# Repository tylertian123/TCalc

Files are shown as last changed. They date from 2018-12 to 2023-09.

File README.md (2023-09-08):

# TCalc
Source code for an STM32 calculator. This repository contains the firmware source code for both the main and keyboard processors as well as the custom schematics.

Some notable features:
* Full math expression display engine
* Multi-function graphing
* Support for custom variable and function definitions
* Basic linear algebra capabilities
* Useful built-in functions such as linear system solver, polynomial regression, etc
* Built-in periodic table with extensive information for every element
* Snake and Tetris mini-games
* [Here's it playing Bad Apple because why not.](https://youtu.be/kNUgEzcHYEs) [[Separate repo here]](https://github.com/tylertian123/tcalc-badapple)

## Gallery

     


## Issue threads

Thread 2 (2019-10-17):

Status light flashes continuously

mincrmatt12, 2019-10-17:
I believe I have assembled it correctly, but the status light continuously flashes and key presses don't work.

tylertian123, 2019-10-18:
Oh that's just the "random light show" feature. Totally not a bug at all. As for why the key presses don't work - during the "random light show" the keyboard is automatically disabled so that you can focus on the beauty of the lights instead of pressing buttons.

mincrmatt12, 2019-10-18:
Is there an option to disable this "feature"? It is getting in the way due to the RNG being rather terrible at being random -- the light show often appears in long bursts.

tylertian123, 2019-10-18:
Yes, you can disable Random Light Show by disconnecting the keyboard.

mincrmatt12, 2019-10-18:
Sounds like a plan; resolving issue internally as "refused to fix"

Closed 2019-10-18.

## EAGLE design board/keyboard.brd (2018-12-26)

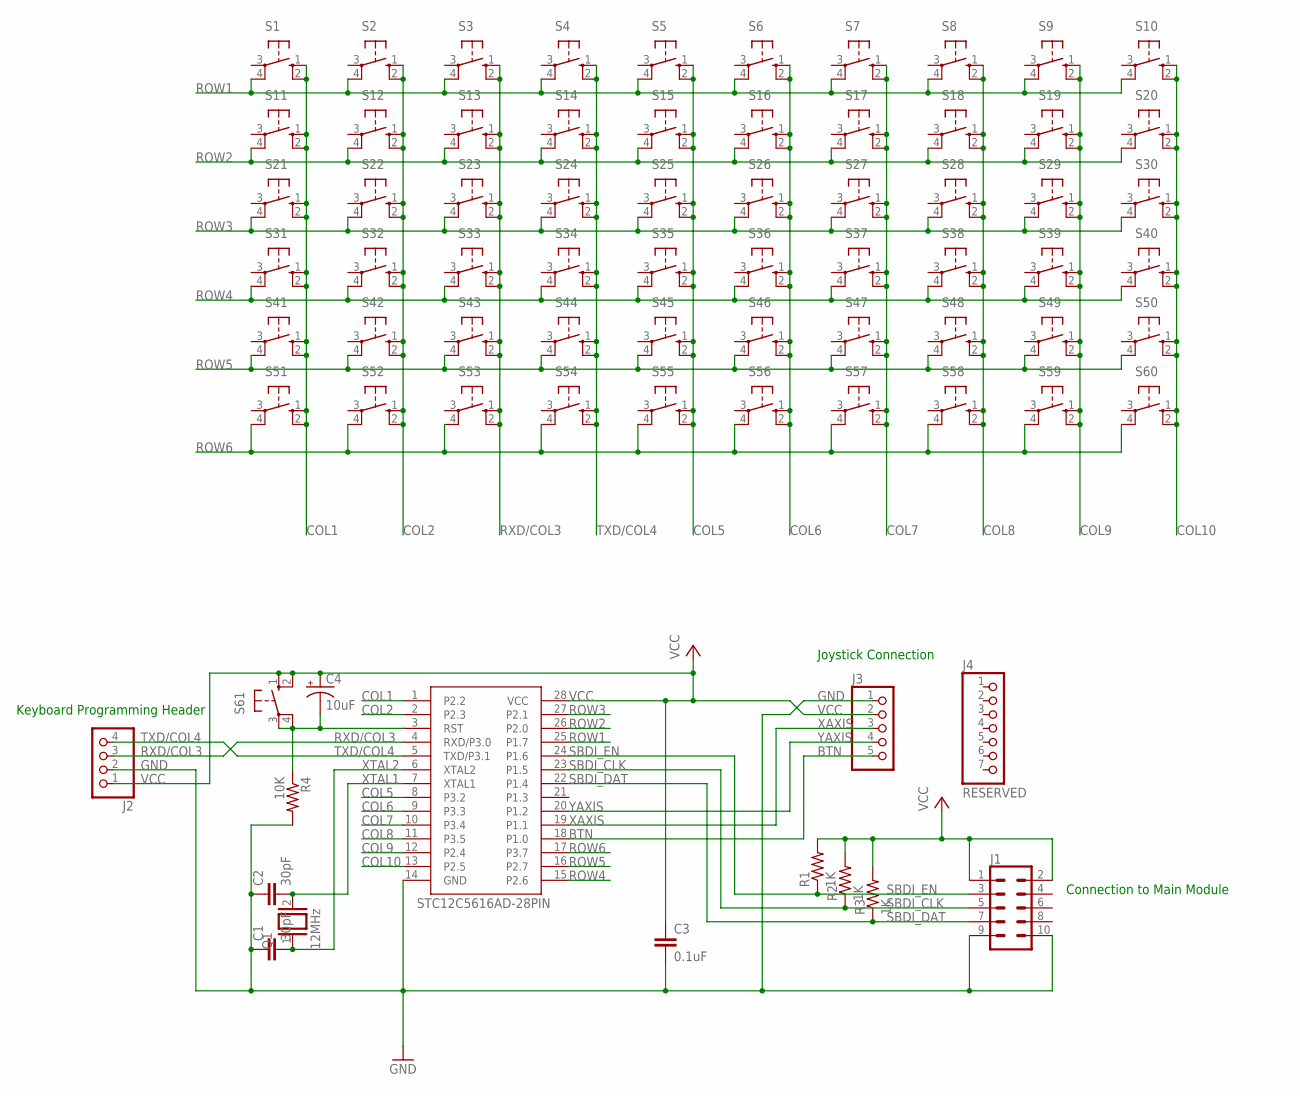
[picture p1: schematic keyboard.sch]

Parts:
C1, C2: 30pF; C025-025X050
C3: 0.1uF; C025-030X050
C4: 10uF; E1,8-4
IC1: STC12C5616AD; DIP787W45P254L3505H508Q28B
J1: CONN_05X2SHD_LOCK; 2X5-SHROUDED_LOCK
J2: PINHD-1X4; 1X04
J3: PINHD-1X5; 1X05
J4: RESERVED; 1X07
Q1: 12MHz; QS
R1, R2, R3: 1K; 0204/7
R4: 10K; 0204/7
S1, S2, S3, S4, S5, S6, S7, S8, S9, S10, S11, S12, S13, S14, S15, S16, S17, S18, S19, S20, S21, S22, S23, S24, S25, S26, S27, S28, S29, S30, S31, S32, S33, S34, S35, S36, S37, S38, S39, S40, S41, S42, S43, S44, S45, S46, S47, S48, S49, S50, S51, S52, S53, S54, S55, S56, S57, S58, S59, S60, S61: 10-XX; B3F-10XX

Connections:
BTN: IC1.18 (P1.0), J3.5
COL1: IC1.1 (P2.2), S1.1 (S), S1.2 (S1), S11.1 (S), S11.2 (S1), S21.1 (S), S21.2 (S1), S31.1 (S), S31.2 (S1), S41.1 (S), S41.2 (S1), S51.1 (S), S51.2 (S1)
COL2: IC1.2 (P2.3), S2.1 (S), S2.2 (S1), S12.1 (S), S12.2 (S1), S22.1 (S), S22.2 (S1), S32.1 (S), S32.2 (S1), S42.1 (S), S42.2 (S1), S52.1 (S), S52.2 (S1)
COL5: IC1.8 (P3.2), S5.1 (S), S5.2 (S1), S15.1 (S), S15.2 (S1), S25.1 (S), S25.2 (S1), S35.1 (S), S35.2 (S1), S45.1 (S), S45.2 (S1), S55.1 (S), S55.2 (S1)
COL6: IC1.9 (P3.3), S6.1 (S), S6.2 (S1), S16.1 (S), S16.2 (S1), S26.1 (S), S26.2 (S1), S36.1 (S), S36.2 (S1), S46.1 (S), S46.2 (S1), S56.1 (S), S56.2 (S1)
COL7: IC1.10 (P3.4), S7.1 (S), S7.2 (S1), S17.1 (S), S17.2 (S1), S27.1 (S), S27.2 (S1), S37.1 (S), S37.2 (S1), S47.1 (S), S47.2 (S1), S57.1 (S), S57.2 (S1)
COL8: IC1.11 (P3.5), S8.1 (S), S8.2 (S1), S18.1 (S), S18.2 (S1), S28.1 (S), S28.2 (S1), S38.1 (S), S38.2 (S1), S48.1 (S), S48.2 (S1), S58.1 (S), S58.2 (S1)
COL9: IC1.12 (P2.4), S9.1 (S), S9.2 (S1), S19.1 (S), S19.2 (S1), S29.1 (S), S29.2 (S1), S39.1 (S), S39.2 (S1), S49.1 (S), S49.2 (S1), S59.1 (S), S59.2 (S1)
COL10: IC1.13 (P2.5), S10.1 (S), S10.2 (S1), S20.1 (S), S20.2 (S1), S30.1 (S), S30.2 (S1), S40.1 (S), S40.2 (S1), S50.1 (S), S50.2 (S1), S60.1 (S), S60.2 (S1)
GND: C1.1, C2.1, C3.2, IC1.14 (GND), J1.9, J1.10, J2.2, J3.1, R4.2
unnamed: C4.-, IC1.3 (RST), R4.1, S61.3, S61.4 (P1)
ROW1: IC1.25 (P1.7), S1.4 (P1), S2.4 (P1), S3.4 (P1), S4.4 (P1), S5.4 (P1), S6.4 (P1), S7.4 (P1), S8.4 (P1), S9.4 (P1), S10.4 (P1)
ROW2: IC1.26 (P2.0), S11.4 (P1), S12.4 (P1), S13.4 (P1), S14.4 (P1), S15.4 (P1), S16.4 (P1), S17.4 (P1), S18.4 (P1), S19.4 (P1), S20.4 (P1)
ROW3: IC1.27 (P2.1), S21.4 (P1), S22.4 (P1), S23.4 (P1), S24.4 (P1), S25.4 (P1), S26.4 (P1), S27.4 (P1), S28.4 (P1), S29.4 (P1), S30.4 (P1)
ROW4: IC1.15 (P2.6), S31.4 (P1), S32.4 (P1), S33.4 (P1), S34.4 (P1), S35.4 (P1), S36.4 (P1), S37.4 (P1), S38.4 (P1), S39.4 (P1), S40.4 (P1)
ROW5: IC1.16 (P2.7), S41.4 (P1), S42.4 (P1), S43.4 (P1), S44.4 (P1), S45.4 (P1), S46.4 (P1), S47.4 (P1), S48.4 (P1), S49.4 (P1), S50.4 (P1)
ROW6: IC1.17 (P3.7), S51.4 (P1), S52.4 (P1), S53.4 (P1), S54.4 (P1), S55.4 (P1), S56.4 (P1), S57.4 (P1), S58.4 (P1), S59.4 (P1), S60.4 (P1)
RXD/COL3: IC1.4 (RXD/P3.0), J2.3, S3.1 (S), S3.2 (S1), S13.1 (S), S13.2 (S1), S23.1 (S), S23.2 (S1), S33.1 (S), S33.2 (S1), S43.1 (S), S43.2 (S1), S53.1 (S), S53.2 (S1)
SBDI_CLK: IC1.23 (P1.5), J1.5, R2.1
SBDI_DAT: IC1.22 (P1.4), J1.7, R3.1
SBDI_EN: IC1.24 (P1.6), J1.3, R1.1
TXD/COL4: IC1.5 (TXD/P3.1), J2.4, S4.1 (S), S4.2 (S1), S14.1 (S), S14.2 (S1), S24.1 (S), S24.2 (S1), S34.1 (S), S34.2 (S1), S44.1 (S), S44.2 (S1), S54.1 (S), S54.2 (S1)
VCC: C3.1, C4.+, IC1.28 (VCC), J1.1, J1.2, J2.1, J3.2, R1.2, R2.2, R3.2, S61.1 (S), S61.2 (S1)
XAXIS: IC1.19 (P1.1), J3.3
XTAL1: C2.2, IC1.7 (XTAL1), Q1.2
XTAL2: C1.2, IC1.6 (XTAL2), Q1.1
YAXIS: IC1.20 (P1.2), J3.4

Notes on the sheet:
Keyboard Programming Header
Joystick Connection
Connection to Main Module

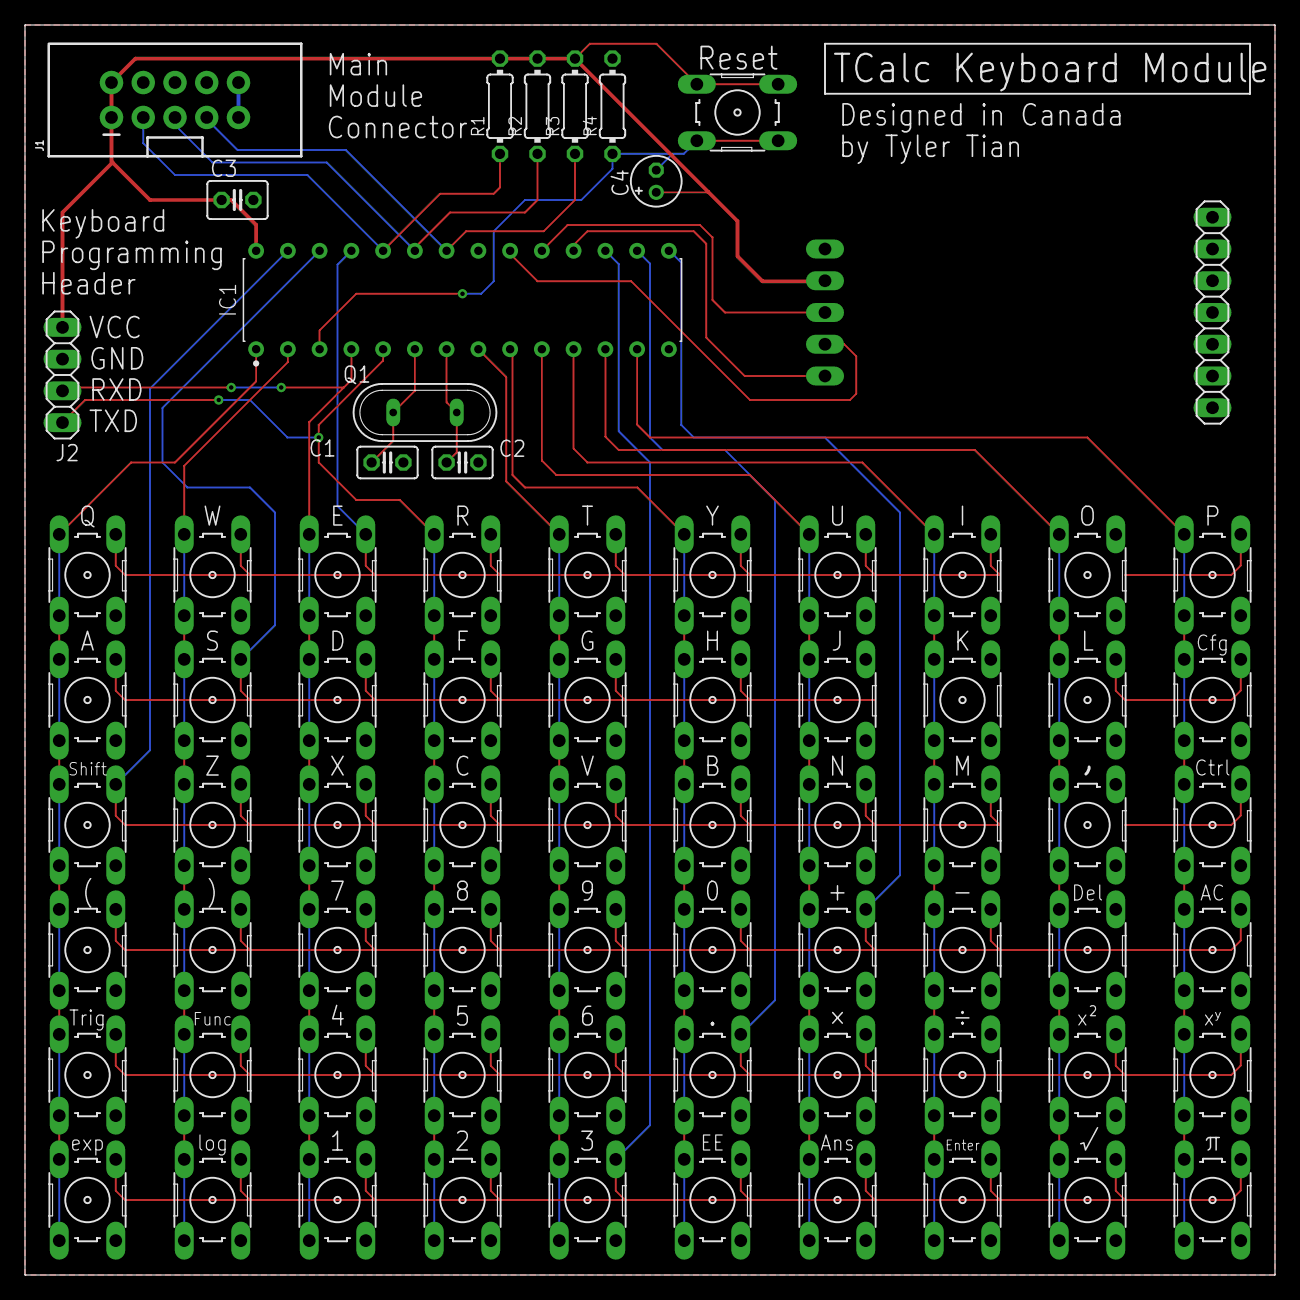
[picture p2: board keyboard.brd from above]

Board: 2 copper layers, 100.0 x 100.0 mm, 75 parts (1 on the bottom side), 27 nets.

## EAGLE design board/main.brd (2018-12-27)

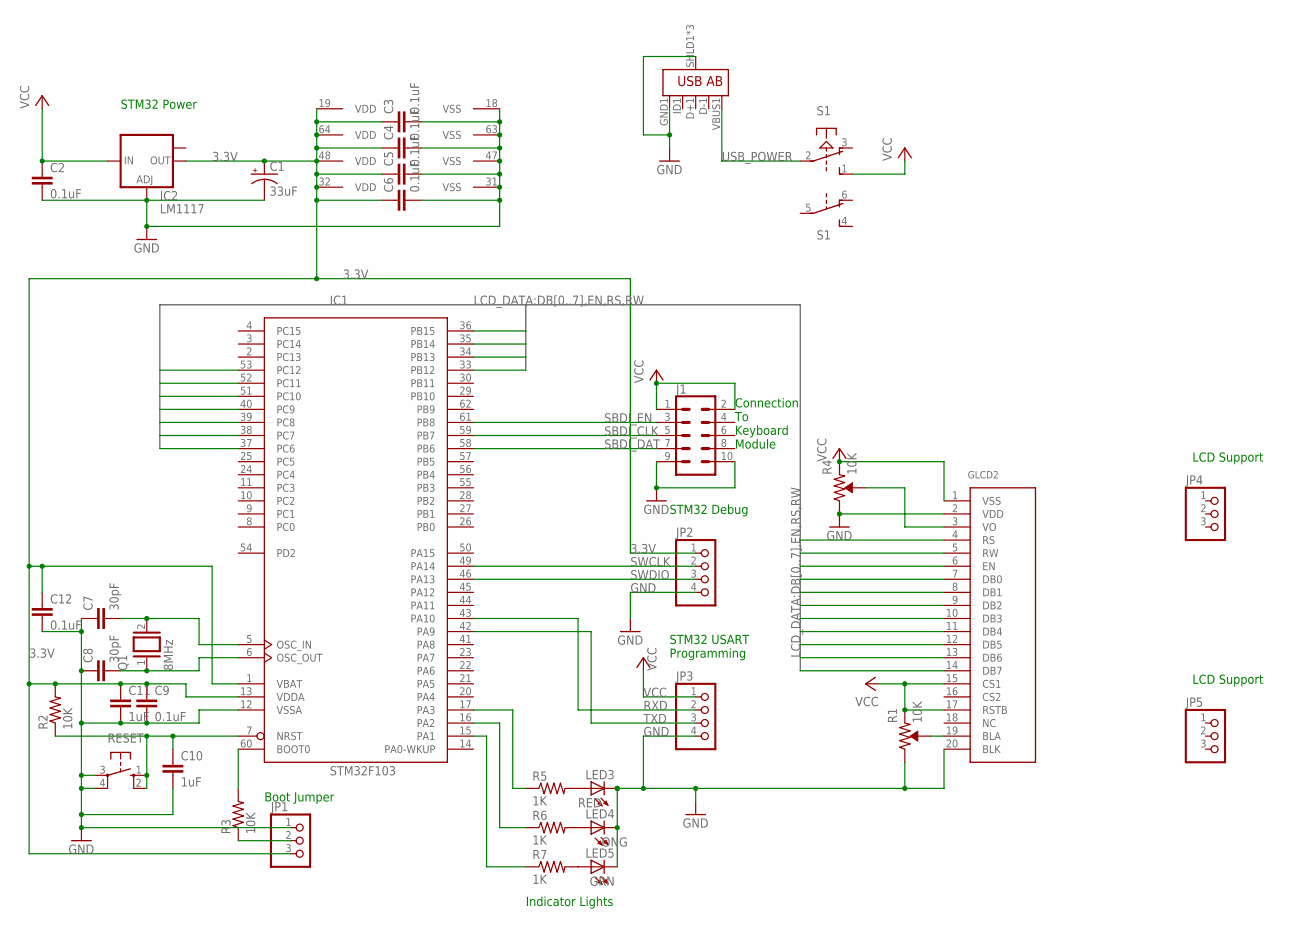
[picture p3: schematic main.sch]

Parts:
C1: 33uF; E2-5
C2, C3, C4, C5, C6, C9, C12: 0.1uF; C025-025X050
C7, C8: 30pF; C025-025X050
C10, C11: 1uF; C025-025X050
GLCD2: LCD128X64; GLCD_TRULY_128X64_20_PINES
IC1: STM32F103; LQFP64
IC2: LM1117; SOT223
J1: CONN_05X2SHD_LOCK; 2X5-SHROUDED_LOCK
JP1, JP4, JP5: PINHD-1X3; 1X03
JP2, JP3: PINHD-1X4; 1X04
LED3: RED; LED5MM
LED4: ONG; LED5MM
LED5: GRN; LED5MM
Q1: 8MHz; QS
R1, R4: 10K; TRIMPOT-PTH-3386U
R2, R3: 10K; 0204/7
R5, R6, R7: 1K; 0204/7
RESET: 10-XX; B3F-10XX
S1: PVA2R
U1: USB_AB_SMT; USB-AB-MICRO-SMD

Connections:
3.3V: C1.+, C3.1, C4.1, C5.1, C6.1, C9.1, C11.1, C12.1, IC1.1 (VBAT), IC1.13 (VDDA), IC1.19 (VDD), IC1.32 (VDD), IC1.48 (VDD), IC1.64 (VDD), IC2.2 (OUT), JP1.3, JP2.1, R2.2
DB0: GLCD2.7 (DB0), IC1.33 (PB12)
DB1: GLCD2.8 (DB1), IC1.34 (PB13)
DB2: GLCD2.9 (DB2), IC1.35 (PB14)
DB3: GLCD2.10 (DB3), IC1.36 (PB15)
DB4: GLCD2.11 (DB4), IC1.37 (PC6)
DB5: GLCD2.12 (DB5), IC1.38 (PC7)
DB6: GLCD2.13 (DB6), IC1.39 (PC8)
DB7: GLCD2.14 (DB7), IC1.40 (PC9)
EN: GLCD2.6 (EN), IC1.53 (PC12)
GND: C1.-, C2.2, C3.2, C4.2, C5.2, C6.2, C7.1, C8.1, C9.2, C10.2, C11.2, C12.2, GLCD2.2 (VDD), GLCD2.20 (BLK), IC1.12 (VSSA), IC1.18 (VSS), IC1.31 (VSS), IC1.47 (VSS), IC1.63 (VSS), IC2.1 (ADJ), J1.9, J1.10, JP1.1, JP2.4, JP3.4, LED3.K (C), LED4.K (C), LED5.K (C), R1.1, R4.1, RESET.3, RESET.4 (P1), U1.GND1 (GND), U1.SHLD1 (SHIELD), U1.SHLD2 (SHIELD), U1.SHLD3 (SHIELD)
unnamed: GLCD2.19 (BLA), R1.2
unnamed: GLCD2.3 (VO), R4.2
unnamed: LED3.A, R5.2
unnamed: LED4.A, R6.2
unnamed: C7.2, IC1.5 (OSC_IN), Q1.2
unnamed: C10.1, IC1.7 (NRST), R2.1, RESET.1 (S), RESET.2 (S1)
unnamed: C8.2, IC1.6 (OSC_OUT), Q1.1
unnamed: IC1.15 (PA1), R7.1
unnamed: IC1.60 (BOOT0), R3.2
unnamed: JP1.2, R3.1
unnamed: IC1.16 (PA2), R6.1
unnamed: IC1.17 (PA3), R5.1
unnamed: LED5.A, R7.2
RS: GLCD2.4 (RS), IC1.51 (PC10)
RW: GLCD2.5 (RW), IC1.52 (PC11)
RXD: IC1.43 (PA10), JP3.2
SBDI_CLK: IC1.59 (PB7), J1.5
SBDI_DAT: IC1.58 (PB6), J1.7
SBDI_EN: IC1.61 (PB8), J1.3
SWCLK: IC1.49 (PA14), JP2.2
SWDIO: IC1.46 (PA13), JP2.3
TXD: IC1.42 (PA9), JP3.3
USB_POWER: S1.2, U1.VBUS1 (VBUS)
VCC: C2.1, GLCD2.1 (VSS), GLCD2.15 (CS1), GLCD2.17 (RSTB), IC2.3 (IN), J1.1, J1.2, JP3.1, R1.3, R4.3, S1.1 (S)

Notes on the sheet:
STM32 Power
Boot Jumper
STM32 Debug
STM32 USART Programming
Indicator Lights
LCD Support
Connection To Keyboard Module

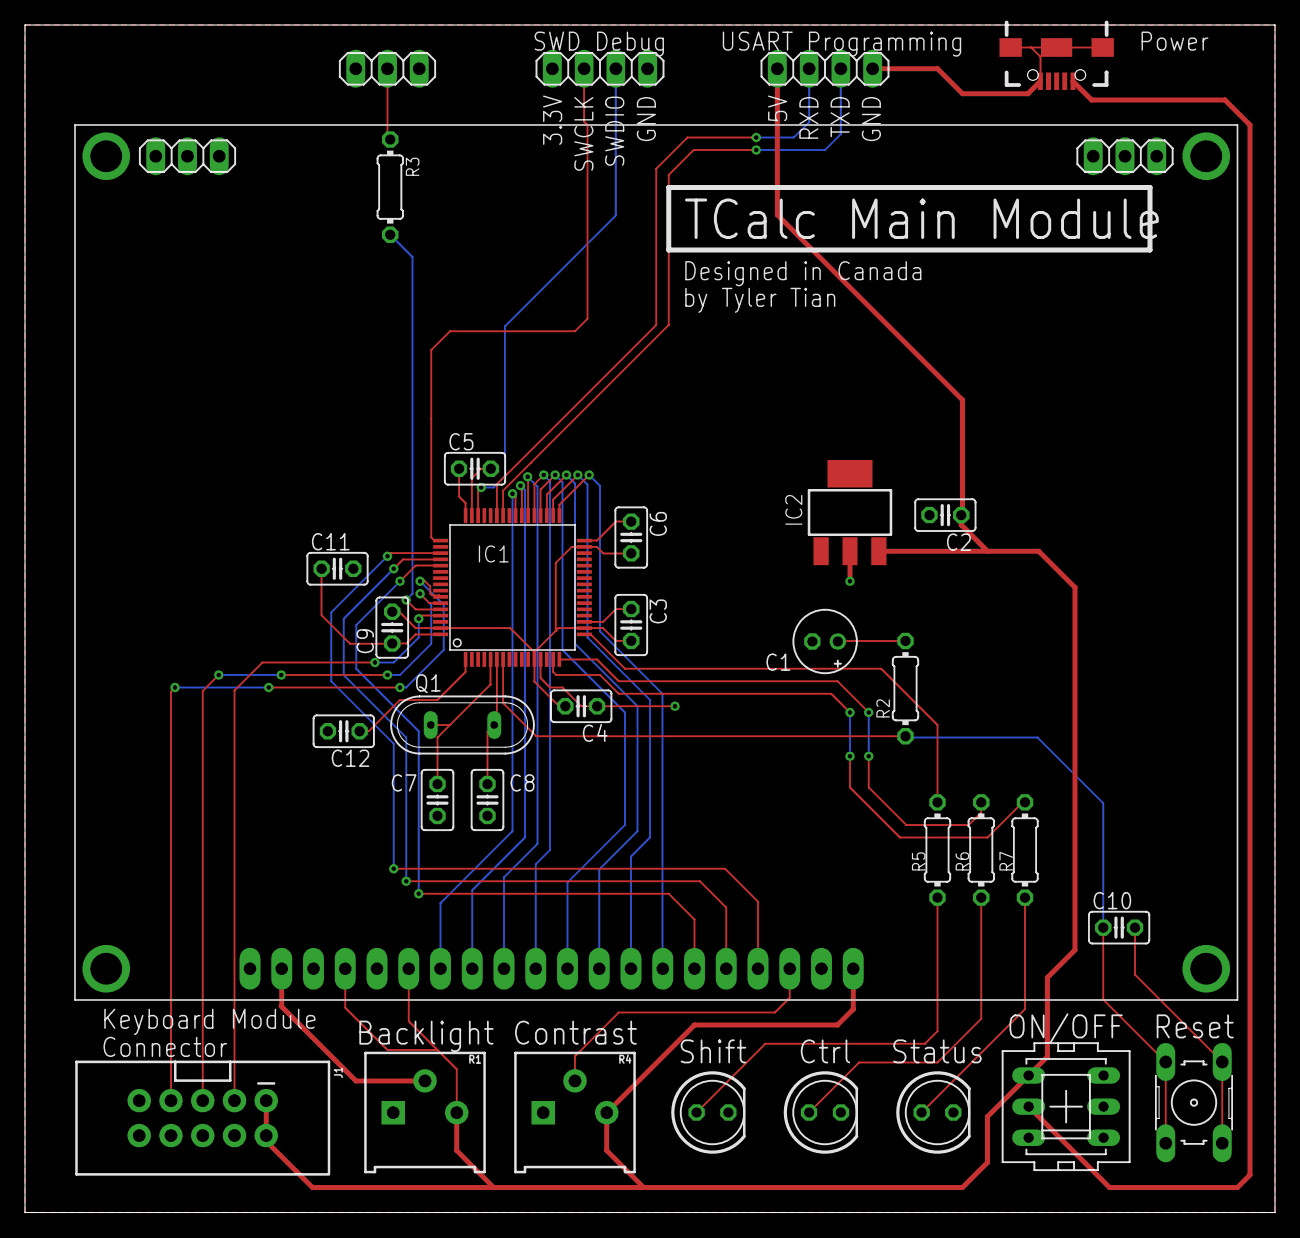
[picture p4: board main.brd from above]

Board: 2 copper layers, 100.0 x 95.0 mm, 35 parts (0 on the bottom side), 35 nets.

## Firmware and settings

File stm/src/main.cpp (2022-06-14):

#include "stm32f10x.h"
#include "delay.hpp"
#include "sys.hpp"
#include <stdio.h>
#include <stdlib.h>
#ifdef _USE_CONSOLE
#define USART_RECEIVE_METHOD_INTERRUPT
#include "console.hpp"
#endif
#include "dynamarr.hpp"
#include "eval.hpp"
#include "exception.hpp"
#include "exprentry.hpp"
#include "gpiopin.hpp"
#include "keydef.h"
#include "keymsg.h"
#include "lcd12864.hpp"
#include "lcd12864_charset.hpp"
#include "neda.hpp"
#include "ntoa.hpp"
#include "sbdi.hpp"
#include "snake.hpp"
#include "tetris.hpp"
#include "usart.hpp"
#include "util.hpp"
#include <inttypes.h>

#define VERSION_STR "V1.5.4"

#ifdef _USE_CONSOLE
#pragma message("Compiling with the USART Console.")
#else
#pragma message("Compiling without the USART Console.")
#endif

#ifdef _TEST_MODE
#pragma message("Compiling with Test Mode.")
#else
#pragma message("Compiling without Test Mode.")
#endif

/********** GPIO Pins and other pin defs **********/
GPIOPin RS(GPIOC, GPIO_Pin_10), RW(GPIOC, GPIO_Pin_11), E(GPIOC, GPIO_Pin_12), D7(GPIOC, GPIO_Pin_9),
        D6(GPIOC, GPIO_Pin_8), D5(GPIOC, GPIO_Pin_7), D4(GPIOC, GPIO_Pin_6), D3(GPIOB, GPIO_Pin_15),
        D2(GPIOB, GPIO_Pin_14), D1(GPIOB, GPIO_Pin_13), D0(GPIOB, GPIO_Pin_12);
lcd::LCD12864 display(RS, RW, E, D0, D1, D2, D3, D4, D5, D6, D7);

GPIOPin SBDI_EN(GPIOB, GPIO_Pin_8);
GPIOPin SBDI_CLK(GPIOB, GPIO_Pin_7);
GPIOPin SBDI_DATA(GPIOB, GPIO_Pin_6);

GPIOPin statusLED(GPIOA, GPIO_Pin_1);
GPIOPin ctrlLED(GPIOA, GPIO_Pin_2);
GPIOPin shiftLED(GPIOA, GPIO_Pin_3);

sbdi::SBDI keyboard(SBDI_EN, SBDI_DATA, SBDI_CLK);

/********** Fault Handlers **********/
extern "C" {

bool displayErrorMessageLine(uint8_t &line, const char *str) {
    display.drawString(0, line * 10, str);

    line++;
    if (line == 6) {
        line = 0;
        display.updateDrawing();
        while (!keyboard.receivePending())
            ;
        keyboard.receive();
        display.clearDrawingBuffer();
        return true;
    }
    return false;
}

void displayErrorMessage(const char *type, uint32_t pc[], const char fn[][64], uint16_t length) {
    constexpr uint16_t CHARS_PER_LINE = 22;

    // Kill off the cursor blink
    TIM_Cmd(TIM3, DISABLE);
    // Reset the keyboard in case it was in analog mode
    keyboard.send32(KEYMSG_RESET);
    while (1) {
        uint8_t line = 0;
        char buf[64];

        display.clearDrawingBuffer();

        displayErrorMessageLine(line, "ERROR: A fatal except-");
        displayErrorMessageLine(line, "ion has occurred.");
        displayErrorMessageLine(line, "Exception Type:");
        displayErrorMessageLine(line, type);
        line++;
        displayErrorMessageLine(line, "**BEGIN STACKTRACE**");

        for (uint16_t i = 0; i < length; i++) {
            // Print the number and program counter
            sprintf(buf, "[%d] - 0x%08" PRIx32 "", i, pc[i]);
            displayErrorMessageLine(line, buf);

            uint8_t len = strlen(fn[i]);
            // Handle line wrapping
            for (uint8_t s = 0; s < len; s += CHARS_PER_LINE) {
                // Copy substring
                strncpy(buf, fn[i] + s, CHARS_PER_LINE);
                // Null terminate if necessary
                if (s + CHARS_PER_LINE < len) {
                    buf[CHARS_PER_LINE] = '\0';
                }
                displayErrorMessageLine(line, buf);
            }
        }

        if (!displayErrorMessageLine(line, "**END STACKTRACE**")) {
            display.updateDrawing();
            while (!keyboard.receivePending())
                ;
            keyboard.receive();
        }
    }
}

void __attribute__((naked)) HardFault_Handler() {
    asm volatile("mrs r0, msp \n"
                 "ldr r2, handler_address \n"
                 "bx r2 \n"

                 "handler_address: .word HardFault_Handler_impl \n");
}

void __attribute__((naked)) UsageFault_Handler() {
    asm volatile("mrs r0, msp \n"
                 "ldr r2, handler_address2 \n"
                 "bx r2 \n"

                 "handler_address2: .word UsageFault_Handler_impl \n");
}

void __attribute__((naked)) BusFault_Handler() {
	asm volatile (
			"mrs r0, msp \n"
			"ldr r2, handler_address3 \n"
			"bx r2 \n"

			"handler_address3: .word BusFault_Handler_impl \n"
	);
}

void HardFault_Handler_impl(uint32_t *stackAtFault) {
    uint32_t PC, SP, LR;
    exception::loadRegsFromFaultTrace(stackAtFault, PC, LR, SP);
    uint16_t backtrace_len = 64;
    uint32_t backtrace[64];
    exception::fillBacktrace(backtrace, backtrace_len, PC, LR, SP);
    char funcnames[backtrace_len][64];
    exception::fillSymbols(funcnames, backtrace, backtrace_len);
    puts("BACKTRACE:");
    for (int i = 0; i < backtrace_len; ++i) {
        printf("[%d] - 0x%08" PRIx32 " <%s>\n", i, backtrace[i], funcnames[i]);
    }
    displayErrorMessage("HardFault", backtrace, funcnames, backtrace_len);
}

void UsageFault_Handler_impl(uint32_t *stackAtFault) {
    uint32_t PC, SP, LR;
    exception::loadRegsFromFaultTrace(stackAtFault, PC, LR, SP);
    uint16_t backtrace_len = 64;
    uint32_t backtrace[64];
    exception::fillBacktrace(backtrace, backtrace_len, PC, LR, SP);
    char funcnames[backtrace_len][64];
    exception::fillSymbols(funcnames, backtrace, backtrace_len);
    puts("BACKTRACE:");
    for (int i = 0; i < backtrace_len; ++i) {
        printf("[%d] - 0x%08" PRIx32 " <%s>\n", i, backtrace[i], funcnames[i]);
    }
    displayErrorMessage("UsageFault", backtrace, funcnames, backtrace_len);
}

void BusFault_Handler_impl(uint32_t *stackAtFault) {
	uint32_t PC, SP, LR; exception::loadRegsFromFaultTrace(stackAtFault, PC, LR, SP);
	uint16_t backtrace_len = 64;
	uint32_t backtrace[64]; exception::fillBacktrace(backtrace, backtrace_len, PC, LR, SP);
	char funcnames[backtrace_len][64]; exception::fillSymbols(funcnames, backtrace, backtrace_len);
	puts("BACKTRACE:");
	for (int i = 0; i < backtrace_len; ++i) {
		printf("[%d] - 0x%08" PRIx32 " <%s>\n", i, backtrace[i], funcnames[i]);
	}
    displayErrorMessage("BusFault", backtrace, funcnames, backtrace_len);
}

// Redefine _exit to allow loading of library
void _exit() {
    // According to specifications this function should never return
    uint32_t PC, SP, LR;
    exception::loadRegsFromCurrentLocation(PC, LR, SP);
    uint16_t backtrace_len = 64;
    uint32_t backtrace[64];
    exception::fillBacktrace(backtrace, backtrace_len, PC, LR, SP);
    char funcnames[backtrace_len][64];
    exception::fillSymbols(funcnames, backtrace, backtrace_len);
    puts("BACKTRACE:");
    for (int i = 0; i < backtrace_len; ++i) {
        printf("[%d] - 0x%08" PRIx32 " <%s>\n", i, backtrace[i], funcnames[i]);
    }

    displayErrorMessage("_fini", backtrace, funcnames, backtrace_len);
}
}

/********** Keyboard stuff **********/
uint64_t keyDataBuffer = 0;
void putKey(uint16_t key) {
    // Store keystroke into buffer
    // If there is already data in the buffer then shift that data left to make room
    if (keyDataBuffer != 0) {
        keyDataBuffer <<= 16;
    }
    keyDataBuffer += (uint16_t) key;
}
uint16_t fetchKey() {
    uint16_t data;
    // Check for key in buffer
    if (keyDataBuffer != 0) {
        data = keyDataBuffer & 0xFFFF;
        keyDataBuffer >>= 16;
        return data;
    }
    // If buffer empty then no new keys have been entered
    else {
        return KEY_NULL;
    }
}

/********** Mode **********/
enum class DispMode {
    NORMAL,
    GAME_SNAKE,
    GAME_TETRIS,
};
DispMode dispMode = DispMode::NORMAL;

/********** Cursor processing **********/
void initCursorTimer(uint16_t period = 2000) {
    RCC_APB1PeriphClockCmd(RCC_APB1Periph_TIM3, ENABLE);
    TIM_TimeBaseInitTypeDef initStruct;
    TIM_TimeBaseStructInit(&initStruct);
    initStruct.TIM_CounterMode = TIM_CounterMode_Up;
    initStruct.TIM_ClockDivision = TIM_CKD_DIV1;
    initStruct.TIM_Prescaler = 17999;
    initStruct.TIM_Period = period;
    initStruct.TIM_RepetitionCounter = 0;
    TIM_TimeBaseInit(TIM3, &initStruct);
    // Set up interrupts
    NVIC_InitTypeDef nvicInit;
    nvicInit.NVIC_IRQChannel = TIM3_IRQn;
    nvicInit.NVIC_IRQChannelCmd = ENABLE;
    nvicInit.NVIC_IRQChannelPreemptionPriority = 0x04;
    nvicInit.NVIC_IRQChannelSubPriority = 0x01;
    NVIC_Init(&nvicInit);
    // Enable timer and interrupts
    TIM_Cmd(TIM3, ENABLE);
    TIM_ITConfig(TIM3, TIM_IT_Update, ENABLE);
}

/********** Cursor flashing and game processing **********/

#define CURSOR_HORIZ_SPACING 1
#define CURSOR_VERT_SPACING 1
expr::ExprEntry mainExprEntry(display, CURSOR_HORIZ_SPACING, CURSOR_VERT_SPACING);

enum class ExprEditMode : uint8_t {
    NORMAL,
    RESULT,
    RESULT_SCROLL,
};
ExprEditMode exprEditMode = ExprEditMode::NORMAL;

extern "C" void TIM3_IRQHandler() {
    if (TIM_GetITStatus(TIM3, TIM_IT_Update)) {
        TIM_ClearITPendingBit(TIM3, TIM_IT_Update);
        // Flash cursor
        if (dispMode == DispMode::NORMAL && exprEditMode == ExprEditMode::NORMAL) {
            mainExprEntry.blinkCursor();
        }
        else if (dispMode == DispMode::GAME_SNAKE) {
            snake::processGame(display);
        }
        else if (dispMode == DispMode::GAME_TETRIS) {
            tetris::processGame(display);
        }
    }
}

#define RESULT_STORE_COUNT 5
// Results of previous computations
eval::Token *calcResults[RESULT_STORE_COUNT] = {nullptr};
// The expressions from previous computations
neda::Container *expressions[RESULT_STORE_COUNT] = {nullptr};
int16_t resultX, resultY;
uint16_t resultWidth = 0, resultHeight = 0;
bool asDecimal = false;
bool asMixedNumber = false;
void drawResult(uint8_t id, bool resetLocation = true) {
    // Display the expression
    display.clearDrawingBuffer();
    expressions[id]->Expr::draw(display);

    // Display the result
    neda::Container *result = new neda::Container();
    eval::toNEDAObjs(result, calcResults[id], mainExprEntry.resultSignificantDigits, asDecimal, asMixedNumber);

    // Set the location of the result
    if (resetLocation) {
        resultX = 128 - CURSOR_HORIZ_SPACING - 1 - result->exprWidth;
        resultY = 64 - CURSOR_VERT_SPACING - result->exprHeight;
        exprEditMode = ExprEditMode::RESULT;
    }
    // Fill the area first
    display.fill(resultX - 1, resultY - 1, result->exprWidth + 2, result->exprHeight + 2, true);
    result->draw(display, resultX, resultY);
    resultWidth = result->exprWidth;
    resultHeight = result->exprHeight;

    // Clean up
    delete result;

    display.updateDrawing();
}

constexpr uint16_t EXPR_SCROLL_SPEED = 4;
uint8_t currentExpr = 0;
void evaluateExpr(neda::Container *);
void normalKeyPressHandler(uint16_t key) {
    if (exprEditMode == ExprEditMode::RESULT) {
        // Special processing for these keys
        switch (key) {
        // Go into result scroll mode
        case KEY_CENTER:
            exprEditMode = ExprEditMode::RESULT_SCROLL;
            break;
        // Show the previous result
        case KEY_UP:
            if (currentExpr < RESULT_STORE_COUNT - 1 && expressions[currentExpr + 1]) {
                ++currentExpr;
                asDecimal = false;
                asMixedNumber = false;
                drawResult(currentExpr);
            }
            break;
        // Show the next result
        case KEY_DOWN:
            if (currentExpr >= 1) {
                --currentExpr;
                asDecimal = false;
                asMixedNumber = false;
                drawResult(currentExpr);
            }
            break;
        // Display the current result with a different method
        case KEY_APPROX:
            asDecimal = !asDecimal;
            if (asDecimal) {
                asMixedNumber = false;
            }
            drawResult(currentExpr);
            break;
        case KEY_FRACFMT:
            asMixedNumber = !asMixedNumber;
            // Since decimal takes precedence over mixed number, set it to false
            if (asMixedNumber) {
                asDecimal = false;
            }
            drawResult(currentExpr);
            break;
        case KEY_DUMMY:
            break;
        // All other keys create a new expression
        default: {
            neda::Container *newExpr;
            // If the key is a left, right, home or end, make a copy of the expression on display
            // Otherwise just insert a new expression
            if (key == KEY_LEFT || key == KEY_RIGHT || key == KEY_HOME || key == KEY_END) {
                newExpr = expressions[currentExpr]->copy();
            }
            else {
                newExpr = new neda::Container();
            }

            // Shift everything back
            if (calcResults[RESULT_STORE_COUNT - 1]) {
                delete calcResults[RESULT_STORE_COUNT - 1];
                delete expressions[RESULT_STORE_COUNT - 1];
                // Set to null pointers
                calcResults[RESULT_STORE_COUNT - 1] = nullptr;
                expressions[RESULT_STORE_COUNT - 1] = nullptr;
            }
            for (uint8_t i = RESULT_STORE_COUNT - 1; i > 0; --i) {
                calcResults[i] = calcResults[i - 1];
                expressions[i] = expressions[i - 1];
            }
            calcResults[0] = nullptr;
            expressions[0] = nullptr;

            newExpr->getCursor(*mainExprEntry.cursor, neda::CURSORLOCATION_END);
            newExpr->x = CURSOR_HORIZ_SPACING + 1;
            newExpr->y = CURSOR_VERT_SPACING + 1;
            exprEditMode = ExprEditMode::NORMAL;
            currentExpr = 0;

            display.clearDrawingBuffer();
            mainExprEntry.adjustExpr();
            mainExprEntry.cursor->expr->drawConnected(display);
            mainExprEntry.cursor->draw(display);
            display.updateDrawing();

            // If any of these keys, insert "Ans" first and then process the key
            if (key == KEY_PLUS || key == KEY_MINUS || key == KEY_MUL || key == KEY_DIV || key == KEY_FRAC ||
                    key == KEY_EQUAL) {
                mainExprEntry.cursor->addStr("Ans");
            }

            // Call the key handler again so the key gets processed
            // Unless the key is enter, in which case only the new expression is created
            if (key != KEY_ENTER) {
                normalKeyPressHandler(key);
            }
        }
        }
    }
    // Otherwise if in scrolling mode
    else if (exprEditMode == ExprEditMode::RESULT_SCROLL) {
        switch (key) {
        case KEY_CENTER:
            exprEditMode = ExprEditMode::RESULT;
            break;
        case KEY_LEFT:
            // Verify that the expression is cut off
            if (resultX < 1) {
                resultX += EXPR_SCROLL_SPEED;
                drawResult(currentExpr, false);
            }
            break;
        case KEY_RIGHT:
            // Verify that the expression is cut off
            if (resultX + resultWidth > 127) {
                resultX -= EXPR_SCROLL_SPEED;
                drawResult(currentExpr, false);
            }
            break;
        case KEY_UP:
            // Verify that the result is cut off
            if (resultY < 1) {
                resultY += EXPR_SCROLL_SPEED;
                drawResult(currentExpr, false);
            }
            break;
        case KEY_DOWN:
            // Verify that the expression is cut off
            if (resultY + resultHeight > 63) {
                resultY -= EXPR_SCROLL_SPEED;
                drawResult(currentExpr, false);
            }
            break;
        case KEY_HOME:
            if (resultX < 1) {
                resultX = 1;
                drawResult(currentExpr, false);
            }
            break;
        case KEY_END:
            if (resultX + resultWidth > 127) {
                resultX = 126 - resultWidth;
                drawResult(currentExpr, false);
            }
            break;
        case KEY_TOP:
            if (resultY < 1) {
                resultY = 1;
                drawResult(currentExpr, false);
            }
            break;
        case KEY_BOTTOM:
            if (resultY + resultHeight > 63) {
                resultY = 62 - resultHeight;
                drawResult(currentExpr, false);
            }
            break;
        // Ignore all other keys
        default:
            break;
        }
    }
    // Normal mode
    else {
        // Special processing for some keys when in normal mode
        if (mainExprEntry.mode == expr::ExprEntry::DisplayMode::NORMAL) {
            switch (key) {
            case KEY_ENTER:
                evaluateExpr(static_cast<neda::Container *>(mainExprEntry.cursor->expr->getTopLevel()));
                asDecimal = false;
                asMixedNumber = false;
                drawResult(0, true);
                break;
            case KEY_APPROX:
                evaluateExpr(static_cast<neda::Container *>(mainExprEntry.cursor->expr->getTopLevel()));
                asDecimal = true;
                asMixedNumber = false;
                drawResult(0, true);
                break;
            // Forward others to handleKeyPress()
            default:
                mainExprEntry.handleKeyPress(key);
                break;
            }
        }
        // For other keys, forward to handleKeyPress()
        else {
            mainExprEntry.handleKeyPress(key);
        }
    }
}
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
int main() {
    // Init system
    sys::initNVIC();
    usart::init(115200);
    printf("******** Welcome to TCalc " VERSION_STR " ********\n");
    printf("Git Commit Hash: " STRINGIFY(_GIT_REV) "\n");
    printf("Built On: " STRINGIFY(_BUILD_TIME) "\n");
    printf("System Core initialization complete.\n");
    printf("Initializing Peripherals...\n");
    // Init LEDs
    statusLED.init(GPIO_Mode_Out_PP, GPIO_Speed_2MHz);
    shiftLED.init(GPIO_Mode_Out_PP, GPIO_Speed_2MHz);
    ctrlLED.init(GPIO_Mode_Out_PP, GPIO_Speed_2MHz);
    statusLED = true;
    shiftLED = false;
    ctrlLED = false;

    // Disable JTAG so we can use PB3 and 4
    RCC_APB2PeriphClockCmd(RCC_APB2Periph_AFIO, ENABLE);
    GPIO_PinRemapConfig(GPIO_Remap_SWJ_JTAGDisable, ENABLE);

    // Initialize display
    display.init();
    display.useExtended();
    display.startDraw();
    display.clearDrawing();

    printf("Generating random seed...\n");
    int randomSeed = getRandomSeed();
    srand(getRandomSeed());
    printf("Random seed: %d\n", randomSeed);
#ifdef _USE_CONSOLE
    printf("Initializing Console...\n");
    console::init();
#else
    printf("This version of TCalc was compiled without the USART console.\n");
#endif

    display.drawString(lcd::SIZE_WIDTH / 2, 25, "TCalc " VERSION_STR,
            lcd::DrawBuf::FLAG_INVERTED | lcd::DrawBuf::FLAG_HALIGN_CENTER);
#ifdef _TEST_MODE
    display.drawString(lcd::SIZE_WIDTH / 2, 50, "Test Mode", lcd::DrawBuf::FLAG_HALIGN_CENTER);
#endif
    display.updateDrawing();

    // Set up SBDI
    keyboard.init();
    // Reset keyboard
    keyboard.send32(KEYMSG_RESET);

    // Title screen delay
    delay::ms(1000);

    if (keyboard.receivePending()) {
        receiveKey(keyboard);
    }

    uint16_t key = KEY_NULL;

    if ((key = fetchKey()) == KEY_LCS) {
        dispMode = DispMode::GAME_SNAKE;
        snake::startGame();

        initCursorTimer(1000);
    }
    else if (key == KEY_LCT || key == KEY_LCY) {
        dispMode = DispMode::GAME_TETRIS;
        tetris::gameState.holdEnabled = key == KEY_LCY;
        tetris::startGame();

        initCursorTimer(1500);
    }

    // Start blink

    display.clearDrawingBuffer();
    if (dispMode == DispMode::NORMAL) {
        initCursorTimer(2000);
        mainExprEntry.adjustExpr();
        mainExprEntry.cursor->expr->drawConnected(display);
        mainExprEntry.cursor->draw(display);
        display.updateDrawing();
    }

    while (true) {
        if ((key = fetchKey()) != KEY_NULL) {
            switch (dispMode) {
            case DispMode::NORMAL:
                normalKeyPressHandler(key);
                break;
            case DispMode::GAME_SNAKE:
                snake::handleKeyPress(key);
                break;
            case DispMode::GAME_TETRIS:
                tetris::handleKeyPress(key, display);
                break;
            }
        }
        else if (keyboard.receivePending()) {
            receiveKey(keyboard);
        }
    }
}

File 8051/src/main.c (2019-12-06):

#include <stc/STC12C5630AD.h>
#include <stdint.h>
#include "sbdi.h"
#include "adc.h"
#include "keydef.h"
#include "keymsg.h"
#include "bmat.h"

SBIT(BUTTON, 0x90);
SBIT(STATUS, 0x93);

#define CHANNEL_X_AXIS 1
#define CHANNEL_Y_AXIS 2

// Configs
#define MIN_THRESH 192
#define MAX_THRESH 832
#define DEFAULT_REPEAT_KEY_DELAY 75
#define DEFAULT_HOLD_COUNTER_MAX 80
uint16_t REPEAT_KEY_DELAY = 75;
uint16_t HOLD_COUNTER_MAX = 80;
bit adcMode = 0;

void delay (unsigned int a){
	unsigned int i;
	while( --a != 0){
		for(i = 0; i < 600; i++);
	}
}

// Keymaps
code const unsigned short KEYMAP_NORMAL[6][10] = {
	{ KEY_LCQ, KEY_LCW, KEY_LCE, KEY_LCR, KEY_LCT, KEY_LCY, KEY_LCU, KEY_LCI, KEY_LCO, KEY_LCP },
	{ KEY_LCA, KEY_LCS, KEY_LCD, KEY_LCF, KEY_LCG, KEY_LCH, KEY_LCJ, KEY_LCK, KEY_LCL, KEY_CONFIG },
	{ KEY_SHIFT, KEY_LCZ, KEY_LCX, KEY_LCC, KEY_LCV, KEY_LCB, KEY_LCN, KEY_LCM, KEY_COMMA, KEY_CTRL },
	{ KEY_LBRACKET, KEY_RBRACKET, KEY_7, KEY_8, KEY_9, KEY_0, KEY_PLUS, KEY_MINUS, KEY_DELETE, KEY_ALLCLEAR },
	{ KEY_TRIG, KEY_CAT, KEY_4, KEY_5, KEY_6, KEY_DOT, KEY_MUL, KEY_DIV, KEY_SQUARE, KEY_EXPONENT },
	{ KEY_EXP, KEY_LOG10, KEY_1, KEY_2, KEY_3, KEY_EE, KEY_ANS, KEY_ENTER, KEY_ROOT, KEY_PI },
};
code const unsigned short KEYMAP_SHIFT[6][10] = {
	{ KEY_Q, KEY_W, KEY_E, KEY_R, KEY_T, KEY_Y, KEY_U, KEY_I, KEY_O, KEY_P },
	{ KEY_A, KEY_S, KEY_D, KEY_F, KEY_G, KEY_H, KEY_J, KEY_K, KEY_L, KEY_SPACE },
	{ KEY_SHIFT, KEY_Z, KEY_X, KEY_C, KEY_V, KEY_B, KEY_N, KEY_M, KEY_FACT, KEY_CTRL },
	{ KEY_ABS, KEY_RBRACKET, KEY_7, KEY_ASTERISK, KEY_9, KEY_0, KEY_SUM, KEY_RARROW, KEY_CLEAR, KEY_ALLCLEAR },
	{ KEY_LOGIC, KEY_RECALL, KEY_4, KEY_5, KEY_6, KEY_DOT, KEY_PRODUCT, KEY_FRAC, KEY_CUBE, KEY_SUB },
	{ KEY_LN, KEY_LOGN, KEY_1, KEY_2, KEY_3, KEY_EE, KEY_ANS, KEY_APPROX, KEY_NTHROOT, KEY_EULER },
};
code const unsigned short KEYMAP_CTRL[6][10] = {
	{ KEY_LCQ, KEY_LCW, KEY_LCE, KEY_LCR, KEY_PTABLE, KEY_LCY, KEY_MU, KEY_LCI, KEY_LCO, KEY_PIECEWISE },
	{ KEY_LCA, KEY_LCS, KEY_LCD, KEY_GFUNCS, KEY_GRAPH, KEY_GSETTINGS, KEY_LCJ, KEY_LCK, KEY_LCL, KEY_CONFIG },
	{ KEY_SHIFT, KEY_LCZ, KEY_LCX, KEY_LCC, KEY_LCV, KEY_LCB, KEY_LCN, KEY_MATRIX, KEY_COMMA, KEY_CTRL },
	{ KEY_LBRACKET, KEY_RBRACKET, KEY_7, KEY_8, KEY_9, KEY_0, KEY_AUGMENT, KEY_MINUS, KEY_CLEARVAR, KEY_ALLCLEAR },
	{ KEY_TRIG, KEY_VRECALL, KEY_4, KEY_5, KEY_6, KEY_DOT, KEY_CROSS, KEY_FRACFMT, KEY_SQUARE, KEY_EXPONENT },
	{ KEY_EXP, KEY_LOG10, KEY_1, KEY_2, KEY_3, KEY_EE, KEY_ANS, KEY_EQUAL, KEY_ROOT, KEY_CONST },
};

bit shift = 0;
bit ctrl = 0;

void checkReceive(void);
void sendKey(unsigned short key) {
	checkReceive();
	STATUS = !STATUS;
	SBDI_BeginTransmission();
	SBDI_SendByte(key >> 8);
	SBDI_SendByte(key & 0x00FF);
	SBDI_EndTransmission();
}
void send(unsigned char row, unsigned char col) {
	// Handle shift and ctrl keys separately
	if(KEYMAP_NORMAL[row][col] == KEY_SHIFT) {
		shift = !shift;
		sendKey(shift ? KEY_SHIFTON : KEY_SHIFTOFF);
		return;
	}
	else if(KEYMAP_NORMAL[row][col] == KEY_CTRL) {
		ctrl = !ctrl;
		sendKey(ctrl ? KEY_CTRLON : KEY_CTRLOFF);
		return;
	}
	
	// Check if shift and ctrl keys are down
	if(shift) {
		// Send the key, delay and deactivate shift and ctrl
		sendKey(KEYMAP_SHIFT[row][col]);
		delay(50);
		sendKey(KEY_SHIFTOFF);
		shift = 0;
	}
	else if(ctrl) {
		sendKey(KEYMAP_CTRL[row][col]);
		delay(50);
		sendKey(KEY_CTRLOFF);
		ctrl = 0;
	}
	else {
		sendKey(KEYMAP_NORMAL[row][col]);
	}
}
void checkAndSend(unsigned char row) {
	unsigned char col = checkCols();
	unsigned char holdCounter = 0;
	if(col == 0xFF) {
		return;
	}
	
	// Key hold checker same logic as joystick's
	send(row, col);
	while(checkCols() == col) {
		if(holdCounter <= HOLD_COUNTER_MAX) {
			holdCounter ++;
			delay(10);
		}
		else {
			send(row, col);
			delay(REPEAT_KEY_DELAY);
		}
	}
}

void checkReceive(void) {
	uint16_t param;
	while(SBDI_ReceivePending()) {
		SBDI_Receive();
		if(SBDI_ReceiveBuffer != 0) {
			param = SBDI_ReceiveBuffer & 0x0000FFFF;
			switch(SBDI_ReceiveBuffer & 0xFFFF0000) {
			case KEYMSG_RESET:
				HOLD_COUNTER_MAX = DEFAULT_HOLD_COUNTER_MAX;
				REPEAT_KEY_DELAY = DEFAULT_REPEAT_KEY_DELAY;
				adcMode = 0;
				break;
			case KEYMSG_SET_HOLD_KEY_DURATION:
				HOLD_COUNTER_MAX = param;
				break;
			case KEYMSG_SET_KEY_REPEAT_DELAY:
				REPEAT_KEY_DELAY = param;
				break;
			case KEYMSG_SET_MODE:
				adcMode = 1;
				break;
			case KEYMSG_SET_ADC_KEY_REPEAT_DELAY:
				REPEAT_KEY_DELAY = param;
				adcMode = 1;
				break;
			default:
				break;
			}
			delay(10);

			SBDI_ReceiveBuffer = 0;
		}
	}
}

void main(void) {
	unsigned short result = 0;
	unsigned char holdCounter = 0;
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

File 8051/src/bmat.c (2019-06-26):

#include "bmat.h"

void bmat_delay (unsigned int a){
	unsigned int i;
	while( --a != 0){
		for(i = 0; i < 600; i++);
	}
}

void resetRows() {
	ROW1 = ROW2 = ROW3 = ROW4 = ROW5 = ROW6 = 1;
}
void resetCols() {
	COL1 = COL2 = COL3 = COL4 = COL5 = COL6 = COL7 = COL8 = COL9 = COL10 = 1;
}

unsigned char checkCols() {
	if(!COL1) {
		// DEBOUNCE(COL1);
		return 0;
	}
	if(!COL2) {
		// DEBOUNCE(COL2);
		return 1;
	}
	if(!COL3) {
		// DEBOUNCE(COL3);
		return 2;
	}
	if(!COL4) {
		// DEBOUNCE(COL4);
		return 3;
	}
	if(!COL5) {
		// DEBOUNCE(COL5);
		return 4;
	}
	if(!COL6) {
		// DEBOUNCE(COL6);
		return 5;
	}
	if(!COL7) {
		// DEBOUNCE(COL7);
		return 6;
	}
	if(!COL8) {
		// DEBOUNCE(COL8);
		return 7;
	}
	if(!COL9) {
		// DEBOUNCE(COL9);
		return 8;
	}
	if(!COL10) {
		// DEBOUNCE(COL10);
		return 9;
	}
	return 0xFF;
}

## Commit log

2018-10-22 Add GPIO configuration changing when switching from reading to writing and vice versa
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2018-10-25 Remove unused code in pwm.cpp and add undef of W_CMD in lcd1602
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2018-10-30 Remove code for secondary LCD
    [Calculator Keyboard Layout.xlsx]
2018-10-30 Add bitmaps for numbers
    [Calculator Keyboard Layout.xlsx]
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2018-11-03 Fix linker errors and try out malloc() and new
    [main.cpp]
2018-11-04 Build basic key exchange program and fix charset
    [lcdbase.cpp, main.cpp]
2018-11-05 Implement neda::FractionExpression methods; bugs present
    [main.cpp]
2018-11-07 Add neda::ExponentExpr (still buggy)
    [main.cpp]
2018-11-07 Fix bugs with the alignment of neda::ExponentExpr
    [main.cpp]
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2018-11-11 Change port defs for hardware in 8051
    [Calculator Keyboard Layout.xlsx]
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2018-11-13 Add 8051 side keyboard code and bitmaps for summation and product
    [Calculator Keyboard Layout.xlsx]
2018-11-13 Add missing destructors for several NEDA classes and declare neda::SigmaPiExpr
    [main.cpp]
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2018-11-18 Fix cursor test code
    [main.cpp]
2018-11-18 Fix bug with neda::ContainerExpr not setting parent of children
    [main.cpp]
2018-11-19 Fix bug with adjustExpr
    [main.cpp]
2018-11-19 Remove neda::Expr::setX and neda::Expr::setY and replace with neda::Expr::updatePosition
    [main.cpp]
2018-11-20 Lower SBDI bus speed to make sure data gets sent properly, fix bug in neda::StringExpr::draw
    [main.cpp]
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2018-11-21 Fix a bunch of errors in NEDA related to StringExprs
    [main.cpp]
2018-11-21 Fix up even more bugs with NEDA and expression entry
    [main.cpp]
2018-11-21 Change key mappings for the mixed number and improper fraction keys
    [Calculator Keyboard Layout.xlsx]
2018-11-22 Fix one of the cases of delete key handling
    [main.cpp]
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2018-11-23 Replace neda::BracketExpr with neda::LeftBracket
2018-11-23 Fix bug in NEDA with brackets
2018-11-23 Fix bug in NEDA bracket height computation
2018-11-24 Separate decl and impl of neda::Cursor and add missing case for neda::Container::left and neda::Container::right
    [main.cpp]
2018-11-25 Fix display adjustment bug
    [main.cpp]
2018-11-26 Fix bug with charset
    [main.cpp]
2018-11-26 Fix error in main.cpp
    [main.cpp]
2018-11-26 Fix bug in LCD fill method
    [main.cpp]
2018-11-26 Fix bug in lcd ANDDrawBufferByte
    [main.cpp]
2018-11-26 Fix bug in trig mode display
    [main.cpp]
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2018-12-09 Fix bugs with NEDA and eval
    [main.cpp]
2018-12-09 Add constant selection menu
    [Calculator Keyboard Layout.xlsx]
2018-12-10 Change pin definitions and fix bugs
    [main.cpp]
2018-12-11 Fix various bugs and add keybind for approx equals key
    [Calculator Keyboard Layout.xlsx]
2018-12-11 Fix off-by-one error in adjustExpr and increase heap size
    [main.cpp]
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2018-12-13 Add missing snake game files and double the size of snake
    [main.cpp]
2018-12-19 Fix expression location bug
    [main.cpp]
2018-12-20 Restore missing character and make user defined function listing more efficient
    [main.cpp]
2018-12-24 Check in eagle schs
    [keyboard.brd, keyboard.sch, main.sch]
2018-12-24 Fix up schematic and finish placing the buttons in the keyboard brd
    [keyboard.brd, keyboard.sch]
2018-12-24 Add joystick support in keyboard schematic
    [keyboard.brd, keyboard.sch]
2018-12-24 Finish placing components
    [keyboard.brd, keyboard.sch]
2018-12-24 Fix schematic button matrix
    [keyboard.brd, keyboard.sch]
2018-12-24 Add most keyboard wires
    [keyboard.brd]
2018-12-24 Finish most of front side of board
    [keyboard.brd]
2018-12-24 Finish basic board design
    [keyboard.brd, keyboard.sch]
2018-12-24 Add silkscreen
    [keyboard.brd]
2018-12-24 Finish keyboard PCB
    [keyboard.brd, keyboard.sch]
2018-12-24 Check in Eagle library
    [keyboard.brd]
2018-12-25 Restore accidentally deleted file
    [keyboard.brd]
2018-12-25 Set up part of main module schematic
    [main.sch]
2018-12-25 Update more of new schematic
    [main.sch]
2018-12-25 Finish basic schematic for main board
    [main.sch]
2018-12-25 Finish basic component placement
    [keyboard.brd, main.brd, main.sch]
2018-12-25 Route some nets in the main board
    [main.brd, main.sch]
2018-12-25 Finish basic routing
    [main.brd]
2018-12-25 Update footprint of LCD
    [main.brd, main.sch]
2018-12-25 Add silkscreen labels
    [main.brd, main.sch]
2018-12-25 Improve silkscreen text
    [main.brd]
2018-12-26 Add key labels to keyboard
    [keyboard.brd]
2018-12-26 Reexport gerbers
    [main.brd]
2018-12-26 Fix errors in main module schematic
    [main.brd, main.sch]
2018-12-26 Partially fix error with LCD library in main board
    [main.brd, main.sch]
2018-12-26 Re-route LCD to fix errors
    [main.brd, main.sch]
2018-12-26 Improve silkscreen
    [main.brd]
2018-12-26 Add reset button to keyboard module
    [keyboard.brd, keyboard.sch]
2018-12-26 Clean up routes by using a 3.3V fill in the main board
    [main.brd]
2018-12-26 Fix error in main schematic
    [main.brd, main.sch]
2018-12-27 Reroute main board
    [main.brd]
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2019-06-25 Change port defs and fix interrupts
    Change port definitions for 8051 for the PCB design. Fix broken
    interrupts by adding calls to GPIO_EXTILineConfig.
    [extipin.cpp, main.cpp]
2019-06-26 Fix comment styles
    Add a space between the // and the comment for single-line comments.
    [adc.c, bmat.c, extipin.cpp]
2019-06-26 Fix bug in neda::Matrix
    Fix bug in neda::Matrix where getTopSpacing() crashes if there are an
    odd number of rows.
    [main.cpp]
2019-06-26 Add matrix entry handlers
    [Calculator Keyboard Layout.xlsx]
2019-06-28 Fix bug with matrix and bracket sizes
    Fix bug where a left bracket would not calculate its size correctly when
    a matrix was first inserted.
    [main.cpp]
2019-07-04 Add built-in function to invert matrices
    [main.cpp]
2019-07-04 Add result scrolling
    Add ability to scroll results that are too wide or too tall to fit on
    the screen.
    [main.cpp]
2019-07-04 Fix NEDA bug
    Fix bug in NEDA where the cursor's location will be wrong sometimes
    after inserting an expression.
    [main.cpp]
2019-07-04 Fix bug with line drawing
    Fix bug where radicals' lines would not be drawn under certain
    circumstances caused by LCD12864::drawLine's signed/unsigned errors.
    [lcdbase.cpp]
2019-07-04 Add __NO_INTERRUPT() macro
    Add new macro __NO_INTERRUPT() that disables all interrupts for the code
    inside. Use this macro instead of __enable_irq() and __disable_irq() and
    also surround new functions with it.
2019-07-05 Fix bug with summation and product
    Fix bug where summation and product won't work with matrices.
    [main.cpp]
2019-07-05 Change ifs to switches in eval code
    Change if...else if...else chains in eval::Operator::operator() into
    switch statements.
2019-07-06 Partially fix misread keystrokes issue
    Partially fix issue where keystrokes are misread by introducing a new
    macro __NO_INTERRUPT().
    [lcdbase.cpp, main.cpp]
2019-07-06 Refactor LCD code and lower SBDI bus speed
    Refactor LCD code to wait indefinitely for busy flag instead of timing
    out and reporting an error via a boolean return value. Lower SBDI bus
    speed by 40% to reduce key misreadings.
    [lcdbase.cpp]
2019-07-06 Fix bug in adjustExpr and UI improvements
    Fix bug in adjustExpr where the expression is placed in the wrong
    location. Improve UI my making the DELETE key go back to normal mode in
    all key handlers.
    [main.cpp]
2019-07-07 Fix bug
    Fix bug where pressing the config key while viewing the result would
    cause the result to be cleared even though it's completely unnecessary.
    [main.cpp]
2019-07-07 Fix incorrect deletes
    Fix use of incorrect deletes over delete[]s.
    [main.cpp]
2019-07-09 UI improvements
    When in normal result view and a button gets pressed, create a new
    expression AND handle that button press normally (except when the button
    is ENTER).
2019-07-09 Fix bug and improve font
    Fix bug in lcd::LCD12864::drawString() and make font look better by
    de-monospacing it.
2019-07-09 Use function pointers in ExprEntry::handleKeyPress()
    Use an array of pointers to member functions in
    ExprEntry::handleKeyPress() instead of a switch statement.
2019-07-10 Fix shift light not turning off issue
    Fix shift light not turning off issue caused by an issue in the SBDI
    bus.
    [main.cpp]
2019-07-11 Change key mappings on keyboard
    Move graph function selection to Ctrl+F and make Ctrl+G graph.
    [Calculator Keyboard Layout.xlsx]
2019-07-11 Increase the limit of functions and variables
    Increase the limit of functions and variables from 255 to 65535. Add
    error detection for functions with more than 255 parameters.
    [main.cpp]
2019-07-12 Create struct eval::Variable
    Create struct eval::Variable to replace the two separate arrays for
    variable names and variable values.
    [main.cpp]
2019-07-12 Update graph function finding code for new algorithm
    Update code that determines what function is graphed onto the cursor's
    current location for the new graphing algorithm. Increment version to
    1.2.1.
2019-07-14 Implement HardFault_Handler()
    Implement HardFault_Handler() to show an error message on the display
    and loop forever. Increment version to 1.2.2.
    [main.cpp]
2019-07-16 Add new characters to LCD charset
    Add new logic operators to LCD charset, including AND, OR, XOR and NOT.
    [Calculator Keyboard Layout.xlsx]
2019-07-17 Add processing for logical NOT
    Add eval support for logical NOT and the framework for other unary
    operators.
2019-07-17 Fix bug with negative sign
    Fix bug where the negative sign will cause a syntax error if used with
    brackets.
2019-07-17 Fix bug introduced by commit 0b8f178
    Fix a bug introduced by commit 0b8f178 where the plus and minus
    operators will always be evaluated as unary operators regardless.
    [main.cpp]
2019-07-17 Add factorial operator
    Add new factorial operator and increment version to 1.2.4.
    [Calculator Keyboard Layout.xlsx]
2019-07-17 Add right arrow character
    Add right arrow character, bound to Shift+-.
    [Calculator Keyboard Layout.xlsx]
2019-07-21 Add key for subscript
    Bind Shift+Exponent to insert a subscript.
    [Calculator Keyboard Layout.xlsx]
2019-07-21 Add null check when calling operators in eval::evaluate()
    When evaluating the expression by calling operators, add null checks in
    case the operation fails.
2019-07-21 Add TRANSPOSE and INVERSE operator types
    Add code for two new operator types, TRANSPOSE and INVERSE which are
    unary operators that operate on matrices. These operators currently
    cannot be entered.
2019-07-21 Add processing for absolute value
    Add processing for absolute value in eval::evaluate(). Increase version
    to 1.2.8 and update keyboard layout.
    [Calculator Keyboard Layout.xlsx]
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2019-07-22 Fix bug in LCD code
    Fix bug in lcd::LCD12864::clearDrawing() that wouldn't reset the display
    buffer, causing the actual display and the display buffer to be out of
    sync.
    [main.cpp]
2019-07-22 Make eval and neda functions const-correct
    Make neda::NEDAObj::getType() const and change functions in eval to take
    const DynamicArrays, const Tokens, etc.
    [main.cpp]
2019-07-22 Add DynamicArray::createConstRef()
    Add a new DynamicArray static method createConstRef() that creates a
    const DynamicArray which just points to the memory specified by two
    iterators, thus avoiding having to allocate more memory and copying over
    elements. Use this new method in evaluate calls().
    Increase the result store count to 5.
    [main.cpp]
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2019-07-24 Add stack overflow check to eval::evaluate
    Add a stack pointer check to eval::evaluate() to make sure that
    recursive functions without an exit condition does not cause a crash
    from stack overflow.
    Add command "stackinfo" to the console, which prints out the stack
    beginning and end addresses, stack size and current stack pointer.
    Increase version to 1.2.11.
    [main.cpp]
2019-07-27 Add new keys
    Add new keys and characters, the asterisk (*, Shift+8) and the matrix
    augment (|, Ctrl+Plus).
    [Calculator Keyboard Layout.xlsx]
2019-07-28 Fix bug with super/subscripts and brackets
    Fix bug with super/subscripts and brackets causing weird height
    calculations in NEDA.
    Increase version to 1.2.12.
    [main.cpp]
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2019-07-30 Replace eval::Fraction and eval::Number
    Replace eval::Fraction and eval::Number with the two-in-one type
    eval::Numerical, which wraps around a util::Numerical.
    Note that this unfortunately kills the ability to turn off auto
    fractions for now.
    [main.cpp]
2019-07-31 Implement the fraction-format key
    Implement the fraction-format key to convert result display method from
    improper fractions to mixed numbers.
    [Calculator Keyboard Layout.xlsx]
2019-08-09 Fix NEDA bug with superscripts and brackets
    Fix NEDA bug where superscript and bracket heights aren't computed
    properly.
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2019-09-04 Fix bug with hidden game
    Fix bug with the activation of the hidden snake game mode.
    [main.cpp]
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2019-09-25 move to pio
    [keyboard.brd, keyboard.sch, main.brd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]
2019-09-26 Fix segfaults
    Fix segmentation faults caused by bugs in the snake game and the
    periodic table functions.
    [main.cpp]
2019-09-27 Fix compile warnings
    Fix compile warnings due to using NULL in memset, adding brackets around
    && and missing default labels in switch statements.
2019-09-27 Fix absolute value bug and improve interface
    Fix the broken absolute value operator and make it so that when the
    fraction button is pressed the expression before it is included in the
    fraction more often.
    [main.cpp]
2019-10-02 Refactor drawString()
    Change the signature of lcd::DrawBuf::drawString() to now accept a set
    of flags telling it what to do (e.g. invert and alignment).
    [main.cpp]
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2019-10-07 Clean up code
    Move main game processing code of snake game into snake.cpp and out of
    main.cpp. Package the fault handler's display error message routine into
    a function.
    [main.cpp]
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2019-10-11 Redirect printf to replace usart::printf
    Redefine _write to use printf directly instead of usart::printf and fix
    heapstats.
    [main.cpp, usart.hpp]
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2019-11-20 Fix SBDI bugs
    Fix bugs with SBDI related to not checking for pending receives when
    sending.
    [main.c]
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2019-12-09 Fix cursor positioning bug
    Fix bug where the position of the expression will be shifted constantly
    if the cursor is too tall to fit on the display.
    [main.cpp]
2019-12-13 Fix format specifier warnings
    Fix compile warnings caused by incorrect format specifiers.
    [main.cpp]
2019-12-16 Fix custom function evaluation
    Fix bug in custom function evaluation code that causes a crash if a
    custom function is evaluated more than one time (as it was accidentally
    deleted after evaluation).
    [main.cpp]
2019-12-18 Fix stack trace thingy
    MATTHEW DOES NOT KNOW HOW TO MULTIPLY 8 BY 4
2019-12-18 Add keyboard reset in fault handler
    Reset the keyboard in the fault handler in case it was in analog mode.
    [main.cpp]
2020-06-05 Fix exponentiation crash and add stricter eval rules
    Fix a crash that happens whenever an exponent is the first token of an
    expression. Improve expression parsing so that all non-infix expressions
    (which sometimes wouldn't be caught by shunting yard) would cause a
    syntax error.
    [main.cpp]
2020-06-30 Make brackets prettier and fix bug
    Make brackets change their curvature based on the height of the
    expression instead of having the same ends no matter how tall it is.
    Fix a bug where the bracket height would not update when a nested
    expression's height updates. This involves moving the call to
    recomputeHeights() inside computeDimensions(), which could have
    unintended consequences but nothing is crashing yet so I guess it's ok?
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2021-05-13 Fix NVIC priority group config
    Use the proper function to configure NVIC preemption and sub-priorities for interrupts.

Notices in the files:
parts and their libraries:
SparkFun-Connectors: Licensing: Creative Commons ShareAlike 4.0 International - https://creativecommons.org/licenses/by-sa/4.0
